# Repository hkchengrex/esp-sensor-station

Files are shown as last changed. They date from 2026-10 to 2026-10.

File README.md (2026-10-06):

# ESP Station

A USB-powered ESP32-C5 station with CO₂, temperature/humidity, radar presence,
and eight mechanical buttons. Firmware publishes MQTT telemetry and Home
Assistant discovery over TLS. Button events contain GPIO identifiers; assign
actions in your own automation system.

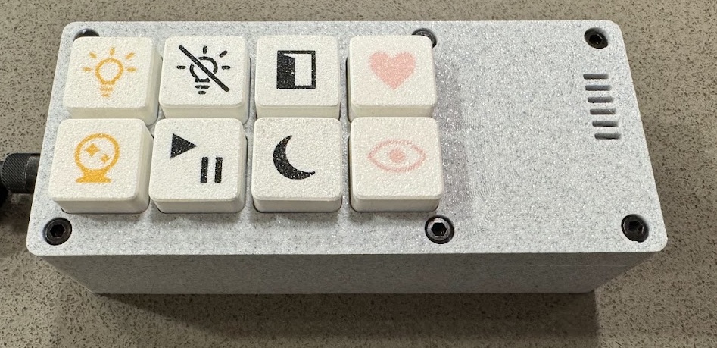
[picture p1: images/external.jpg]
External


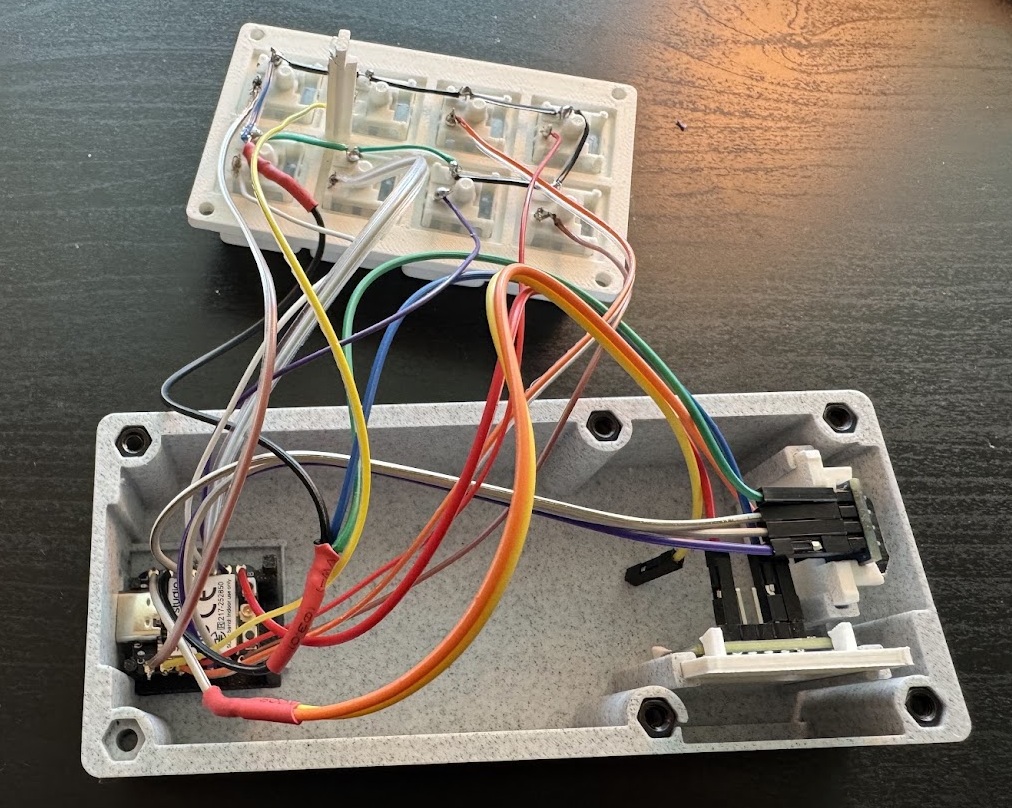
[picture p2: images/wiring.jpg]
Wiring

(forgive my poor soldering)

## Bill of materials

| Part | Quantity |
| --- | ---: |
| Seeed Studio XIAO ESP32-C5, with antenna | 1 |
| Sensirion SCD4x CO₂ sensor breakout, 3.3 V I²C | 1 |
| Hi-Link LD2410C radar module | 1 |
| MX-compatible mechanical switches | 8 |
| 3d printed parts | 1 set |

## Wiring

Wiring diagram

## Firmware

Use ESP-IDF **6.0.2**. Add your broker's public CA certificate as
`firmware/main/certs/mqtt_ca.crt`, then run from an ESP-IDF terminal:

```sh
cd firmware
idf.py set-target esp32c5
idf.py menuconfig
idf.py build
idf.py -p PORT flash
python tools/provision.py --port PORT wifi
python tools/provision.py --port PORT mqtt
```

Replace `PORT` with the board's USB serial port. Setup prompts for credentials;
passwords are hidden and saved only in the device's encrypted NVS. First boot
provisions an HMAC key in eFuse KEY0. See [wiring and firmware details](firmware/README.md).

## Models and printing

Editable FreeCAD models are in [`models/`](models/). Bambu Studio projects are in
[`print/`](print/):

- `01_Enclosure_and_Mounts_0.4mm.3mf`: base, lid, switch plate, ESP32 carrier,
  CO₂ carrier and radar carrier together on one plate.
- `02_Keycaps_AMS_0.2mm.3mf`: twelve distinct icons on one plate, with
  identical 18 × 18 × 9 mm bodies, white PLA and black inlays.

The enclosure plate uses a 0.4 mm nozzle. The keycap plate uses a 0.2 mm nozzle
and AMS. Select any eight icons for the station.

The icons are bulb, crossed bulb, moon, door, start/pause, heart, crystal ball,
eye, solid triangle, solid square, solid circle and arrow-door. Each icon appears
once in the [editable model and print project](models/README.md). Only the icon
differs; the outer profile and switch socket are shared by every cap.

Open the 3MF in Bambu Studio, select your printer/filaments and slice before
printing. Models retain their native editable features. The enclosure is
130 × 56 × 38 mm, excluding keycap height.

**Design limitation:** the base's top-open nut pockets do not capture the nuts
vertically, so the screw-fastened lid can lift out with them. Add a suitable
retention method before relying on the enclosure closure.

## License

Original firmware, tools and documentation: [MIT](LICENSES/MIT.txt).
Models, print projects and preview images: [CC0-1.0](LICENSES/CC0-1.0.txt).
Vendored sensor driver code retains its [third-party license](THIRD_PARTY.md).

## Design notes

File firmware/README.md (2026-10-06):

# Wiring and operation

Wiring diagram

| Connection | XIAO pad | GPIO |
| --- | --- | ---: |
| CO₂ SDA | D4 | 23 |
| CO₂ SCL | D5 | 24 |
| Radar TX → board RX | D7 | 12 |
| Button signals | D0, D1, D2, D3, D6, D8, D9, D10 | 1, 0, 25, 7, 11, 8, 9, 10 |

Power the SCD4x breakout from 3V3 and the LD2410C from 5V/VBUS. Connect both
sensor grounds directly to XIAO GND. The I²C pull-ups must use 3.3 V. The radar
uses UART1 at 256000 baud, 8N1; its RX and OUT pins are unused.

Each switch connects its GPIO to a shared switch return. Connect that return
to XIAO GND through one 1 kΩ resistor. Application UART logging is disabled.
The diagram shows the XIAO's top-view pad layout; sensor blocks are schematic.
Check the actual breakout pin labels before connecting power.

Buttons use internal pull-ups, 10 ms polling and 30 ms debounce. The event topic
reports both `press` and `release`; use `press` for immediate actions. Holding a
button does not repeat it. The separate action topic reports armed releases.
No physical button-to-function mapping is included.

The device identifies itself as `esp-c5-<MAC>` and publishes under
`esp-monitor/<device-id>/`:

| Suffix | Content |
| --- | --- |
| `availability` | Retained online/offline status |
| `state` | CO₂ ppm, temperature °C, humidity %, validity and sample time |
| `presence` | Moving/occupied flags, validity and distance |
| `buttons/event` | GPIO, pad, press/release, boot ID and sequence |
| `buttons/action` | Accepted release actions |
| `buttons/status` | Input mask, debounce/poll intervals and dropped-event counts |
| `calibration/command`, `calibration/result` | Guarded SCD4x calibration requests/results |

Air readings publish every 30 seconds; presence updates every 200 ms. Deduplicate
button events by `(boot_id, sequence)`. MQTT uses QoS 1 and button events are not
retained. The onboard LED follows fresh moving-target reports independently of
network connectivity. Wi-Fi modem power saving remains enabled.

`tools/provision.py` requires `pyserial` (`python -m pip install -r tools/requirements.txt`).
Create a broker user before MQTT setup and grant it access to its device namespace
and the Home Assistant discovery topics. Provision Wi-Fi first, then MQTT. The
broker CA is compiled into the firmware; credentials are entered locally over USB.

For an already provisioned board with this partition layout, update only the app:

```sh
idf.py build
python -m esptool --chip esp32c5 --port PORT --before usb-reset --after hard-reset write-flash --flash-mode dio --flash-size 8MB --flash-freq 80m 0x10000 build/esp_station.bin
python tests/hardware_usb.py --port PORT --cycles 0
```

The C5 rev1.0 USB-reset clock workaround is included. Never erase flash merely
to update the app; doing so removes saved credentials. OTA is not configured.
The optional UDP movement receiver is disabled by default.

Host checks (Linux/WSL with a C compiler):

```sh
python3 tests/host/test_components.py
cc -std=c11 -Wall -Wextra -Werror -Imain tests/test_radar.c main/radar.c -o /tmp/station-radar
/tmp/station-radar
cc -std=c11 -Wall -Wextra -Werror -Imain tests/test_buttons.c -o /tmp/station-buttons
/tmp/station-buttons
python3 -m unittest discover -s tests -p test_provision.py
```

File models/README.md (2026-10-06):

# Models and printing

Open `Station.FCStd` in FreeCAD 1.1 for the base, lid, switch plate and carriers.
Open `Keycaps.FCStd` for the twelve keycaps. Each named icon group contains its
native editable body, sketches and inlays. The station document's eight keycaps
are assembly references. Editing CAD does not automatically update the saved 3MF.

## Keycaps

`../print/02_Keycaps_AMS_0.2mm.3mf` contains one of each icon on a single plate.
Every cap has the same 18 × 18 × 9 mm outer profile, skirt and MX socket.

| Plate row, front to back | Icons, left to right |
| --- | --- |
| 1 | Bulb, crossed bulb, moon, door |
| 2 | Start/pause, heart, crystal ball, eye |
| 3 | Solid triangle, solid square, solid circle, arrow-door |

Use the A1 0.2 mm nozzle, 0.10 mm layers, four walls, 20% gyroid, no supports or
object brim, and a prime tower. Keep the face-down orientation. Slot 1 is white
PLA; slot 2 is black PLA for the 0.52 mm deep inlays. Colour-change purge volumes
are 172 mm³ white to black and 652 mm³ black to white. Select the eight icons you
want, or print all twelve.

## Enclosure and mounts

The base, lid, switch plate and all three electronics carriers share one plate in
`../print/01_Enclosure_and_Mounts_0.4mm.3mf`: 0.16 mm layers, four walls,
20% gyroid, and no support or brim. Keep the stored orientations.

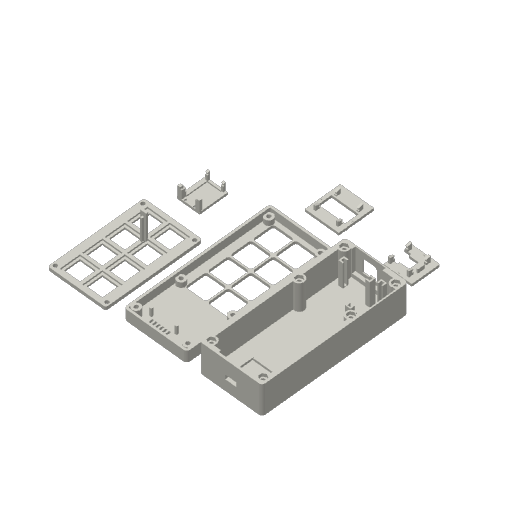
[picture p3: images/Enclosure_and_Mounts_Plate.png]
Enclosure and mounts plate


Both projects have been sliced and reopened through Bambu Studio's CLI. Desktop
preset persistence has not been checked. On opening, confirm the nozzle, layer
height, walls, infill, supports, brim and filament slots above before printing.

The base has open nut pockets without vertical capture. Its lid needs an added
retention method. Test switch socket and carrier fit with your hardware; fit and
material performance depend on the printer and electronics breakout.

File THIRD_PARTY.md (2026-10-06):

# Third-party code

`firmware/vendor/scd4x/` contains the Sensirion SCD4x I²C driver at commit
`b52cebe1bb1b7050feaac75d7cd33e56c6a8a4e9` from
[Sensirion/embedded-i2c-scd4x](https://github.com/Sensirion/embedded-i2c-scd4x).
Its BSD-3-Clause license and copyright notices are preserved in that directory.

ESP-IDF and the locked Espressif MQTT/cJSON components are downloaded by the
build system and retain their respective licenses; they are not bundled here.

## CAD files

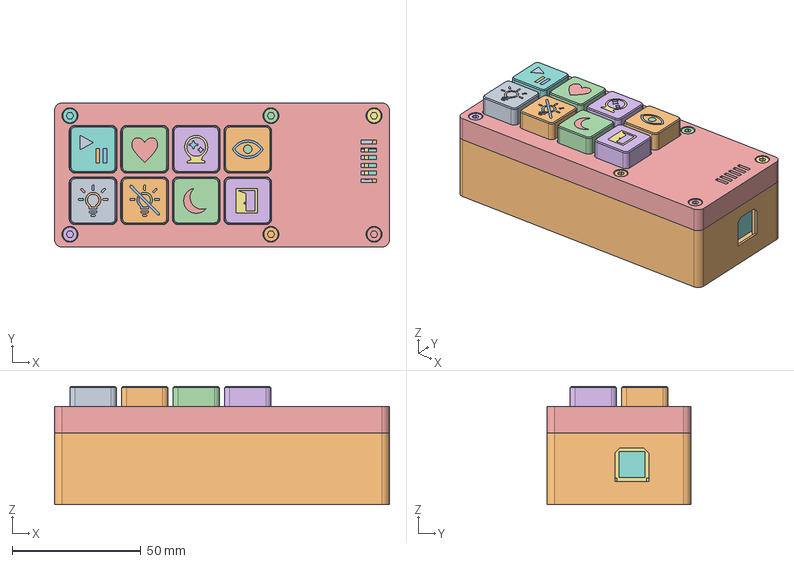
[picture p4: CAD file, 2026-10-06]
models/Station.FCStd
130.0 x 56.0 x 45.9 mm
Removable XIAO carrier - USB-C to left
01 Base - sensor guide rails and left USB-C
REFERENCE - XIAO bare PCB
03 Switch plate - eight switches and ESP32 hold-down
02 Lid - sensor retention, six shared screws
REFERENCE switch 1 - approximate housing
REFERENCE switch 1 stem
REFERENCE switch 2 - approximate housing
REFERENCE switch 2 stem
REFERENCE switch 3 - approximate housing
REFERENCE switch 3 stem
REFERENCE switch 4 - approximate housing
REFERENCE switch 4 stem
REFERENCE switch 5 - approximate housing
REFERENCE switch 5 stem
REFERENCE switch 6 - approximate housing
REFERENCE switch 6 stem
REFERENCE switch 7 - approximate housing
REFERENCE switch 7 stem
REFERENCE switch 8 - approximate housing
REFERENCE switch 8 stem
REFERENCE M3 x 10 socket screw 1
REFERENCE M3 nut 1
REFERENCE M3 x 10 socket screw 2
REFERENCE M3 nut 2
REFERENCE M3 x 10 socket screw 3
REFERENCE M3 nut 3
REFERENCE M3 x 10 socket screw 4
REFERENCE M3 nut 4
REFERENCE XIAO shield
REFERENCE USB socket
03 Radar carrier - tapered anti-rattle contact ribs
04 CO2 carrier - tapered anti-rattle contact ribs
REFERENCE Radar_PCB
REFERENCE Radar_Header
REFERENCE 30 x 12 mm FPC antenna, final antenna size and routing pending
REFERENCE M3 x 10 screw 5
REFERENCE M3 nut 5
REFERENCE M3 x 10 screw 6
REFERENCE M3 nut 6
CO2 rear straight header - 4 x 2.54 mm
CO2 4-pin plug allowance 11.2 x 4; 16 mm total rear projection
CO2 straight pin 1
CO2 straight pin 2
CO2 straight pin 3
CO2 straight pin 4
REFERENCE CO2 PCB - measured 21.75 mm height
REFERENCE CO2 sensor - 2.10 mm from PCB bottom
REFERENCE 1. Light bulb body
REFERENCE 1. Light bulb inlay 1
REFERENCE 1. Light bulb inlay 2
REFERENCE 1. Light bulb inlay 3
REFERENCE 1. Light bulb inlay 4
REFERENCE 1. Light bulb inlay 5
REFERENCE 1. Light bulb inlay 6
REFERENCE 1. Light bulb inlay 7
REFERENCE 1. Light bulb inlay 8
REFERENCE 2. Light bulb off body
REFERENCE 2. Light bulb off inlay 1
REFERENCE 2. Light bulb off inlay 2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

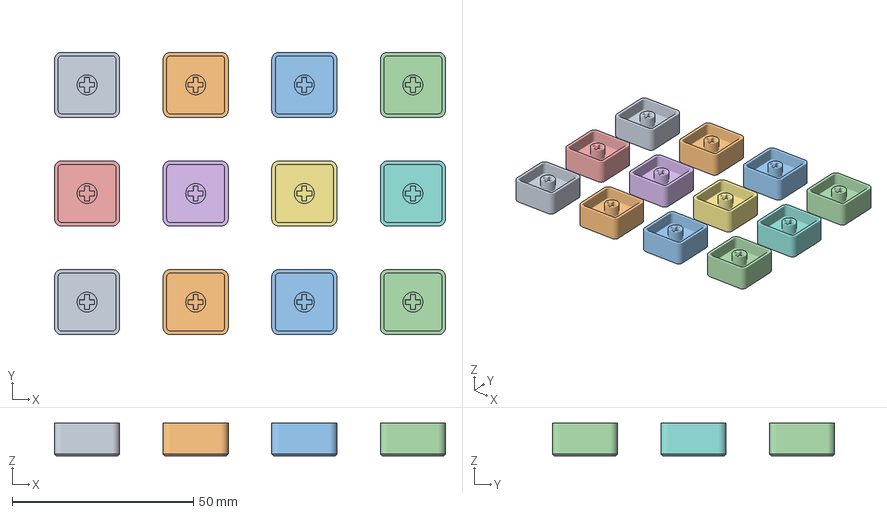
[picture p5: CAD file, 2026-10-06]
print/02_Keycaps_AMS_0.2mm.3mf
108.0 x 78.0 x 9.00 mm
01 Bulb
02 Crossed bulb
03 Moon
04 Door
05 Start pause
06 Heart
07 Crystal ball
08 Eye
09 Triangle
10 Square
11 Circle
12 Arrow door

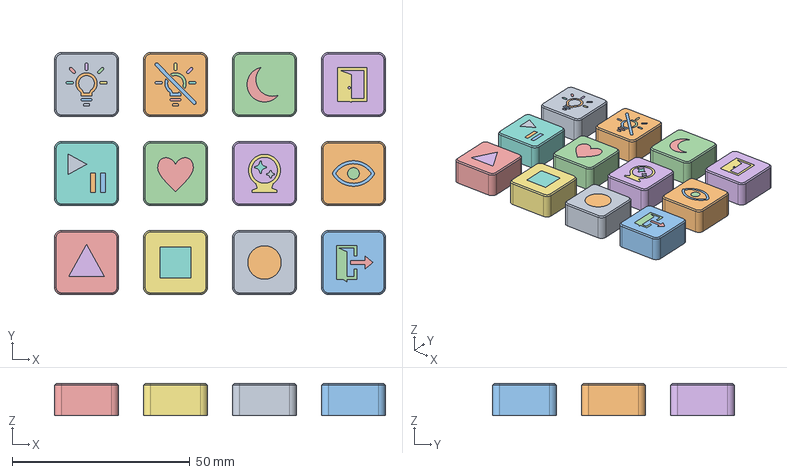
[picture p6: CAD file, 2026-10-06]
models/Keycaps.FCStd
93.0 x 68.0 x 9.00 mm
Bulb - body
Bulb - icon 1
Bulb - icon 2
Bulb - icon 3
Bulb - icon 4
Bulb - icon 5
Bulb - icon 6
Bulb - icon 7
Bulb - icon 8
Crossed bulb - body
Crossed bulb - icon 1
Crossed bulb - icon 2
Crossed bulb - icon 3
Crossed bulb - icon 4
Crossed bulb - icon 5
Crossed bulb - icon 6
Crossed bulb - icon 7
Crossed bulb - icon 8
Crossed bulb - icon 9
Moon - body
Moon - icon 1
Door - body
Door - icon 1
Start pause - body
Start pause - icon 1
Start pause - icon 2
Start pause - icon 3
Heart - body
Heart - icon 1
Crystal ball - body
Crystal ball - icon 1
Crystal ball - icon 2
Crystal ball - icon 3
Eye - body
Eye - icon 1
Eye - icon 2
Triangle - body
Triangle - icon 1
Square - body
Square - icon 1
Circle - body
Circle - icon 1
Arrow door - body
Arrow door - icon 1
Arrow door - icon 2

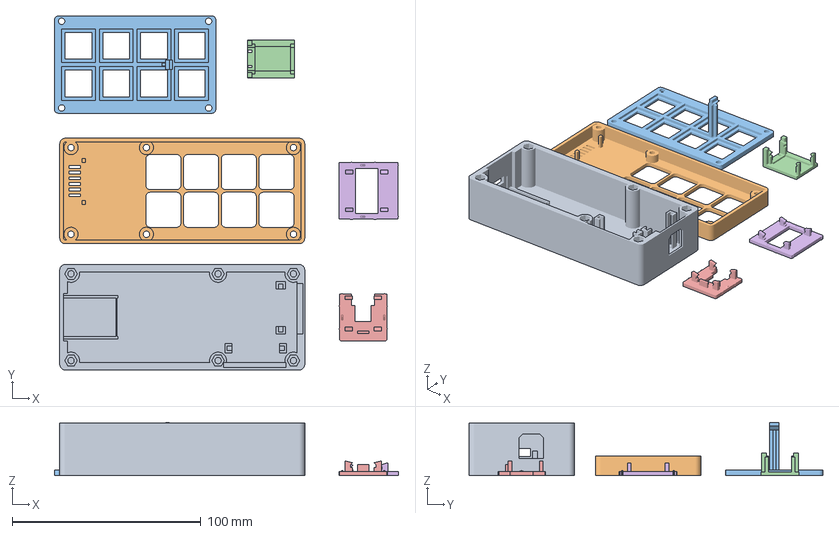
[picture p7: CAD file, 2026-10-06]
print/01_Enclosure_and_Mounts_0.4mm.3mf
182.5 x 187.8 x 28.2 mm
Base
Lid
Switch plate
ESP32 carrier
CO2 carrier
Radar carrier

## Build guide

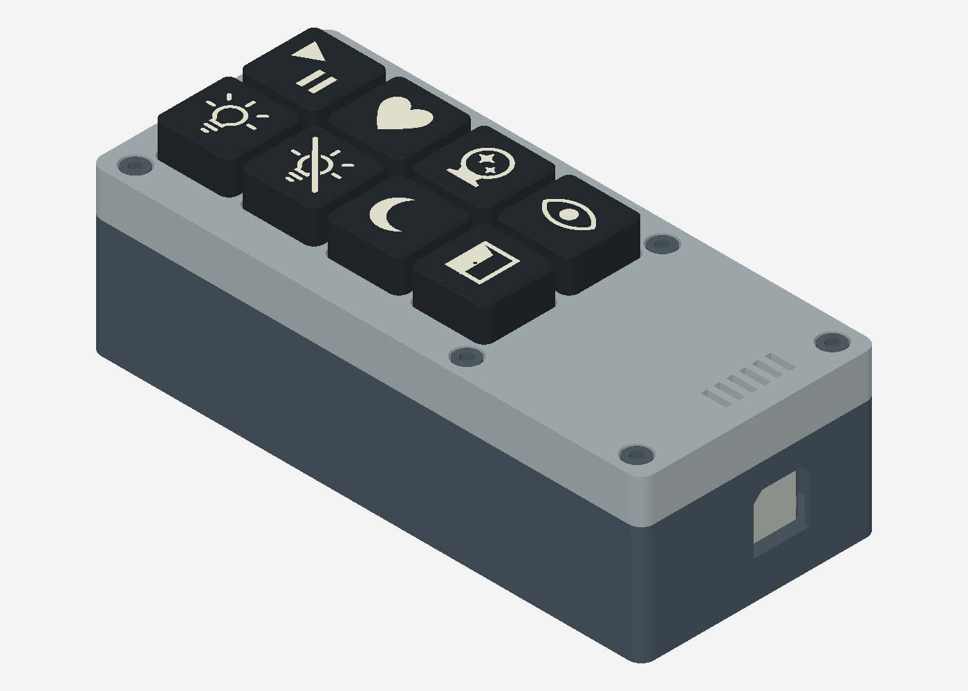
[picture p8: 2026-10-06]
images/Station_Assembly.png

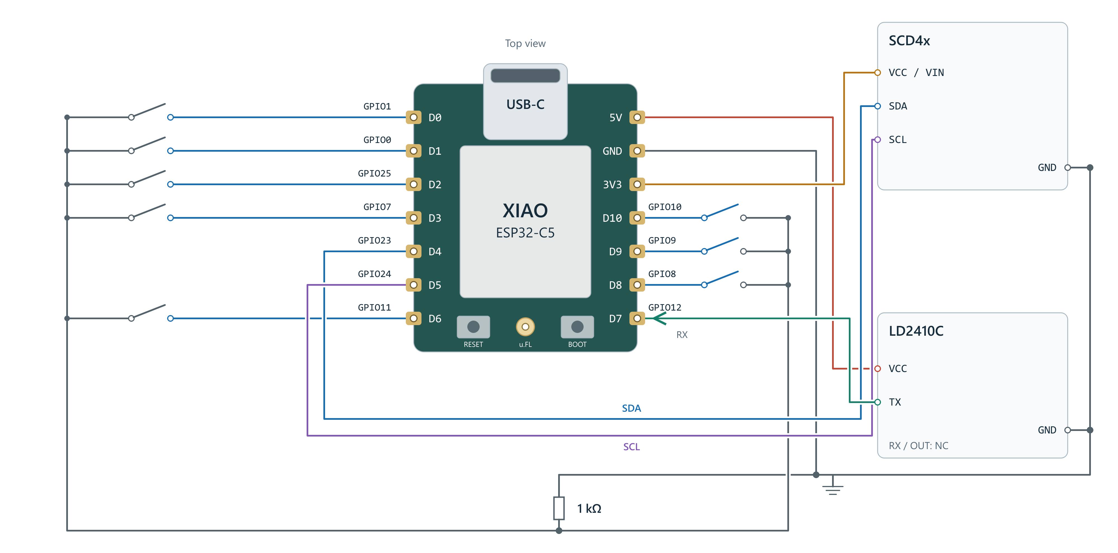
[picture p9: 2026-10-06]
images/Wiring_Diagram.png

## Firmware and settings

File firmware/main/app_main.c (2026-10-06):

#include <inttypes.h>
#include <stdio.h>
#include <time.h>
#include "credential_store.h"
#include "station.h"
#include "buttons.h"
#include "wifi_manager.h"
#include "mqtt_connection.h"
#include "ha_discovery.h"
#include "usb_provisioning.h"
#include "esp_event.h"
#include "esp_chip_info.h"
#include "esp_private/startup_internal.h"
#include "hal/uart_ll.h"
#include "esp_log.h"
#include "esp_mac.h"
#include "esp_netif.h"
#include "esp_netif_sntp.h"
#include "esp_timer.h"
#include "esp_wifi.h"
#include "freertos/FreeRTOS.h"
#include "freertos/task.h"

// ESP32-C5 rev1.0 ROM waits for UART0_READY even when flashing over USB.
// IDF 6.0.2 gates this clock when the UART console is disabled; a USB core
// reset preserves that state and then hangs in ROM. Restore only the clocks
// early in startup. Do not install UART0 or route its TX onto button GPIO11.
// https://github.com/espressif/esp-idf/issues/18089
ESP_SYSTEM_INIT_FN(keep_c5_usb_reset_working, CORE, BIT(0), 100)
{
    esp_chip_info_t chip;
    esp_chip_info(&chip);
    if (chip.model == CHIP_ESP32C5 && chip.revision == 100) {
        uart_ll_enable_bus_clock(UART_NUM_0, true);
        uart_ll_sclk_enable(UART_LL_GET_HW(UART_NUM_0));
    }
    return ESP_OK;
}

extern const uint8_t mqtt_ca_crt_start[] asm("_binary_mqtt_ca_crt_start");
static char s_device_id[32];
static char s_state_topic[128];
static char s_availability_topic[128];
static const char *TAG = "esp_monitor";

static bool time_ready(void)
{
    return time(NULL) > 1735689600;
}

static bool wait_for_time(void)
{
    return time_ready() || esp_netif_sntp_sync_wait(pdMS_TO_TICKS(15000)) == ESP_OK;
}

static void application_task(void *arg)
{
    (void)arg;
    uint32_t published_generation = 0;

    int64_t next_start = 0;
    for (;;) {
        int64_t now = esp_timer_get_time();
        if (wifi_manager_is_connected() && time_ready() && now >= next_start) {
            // Handles delayed Wi-Fi or clock recovery even when boot was offline.
            (void)mqtt_connection_start_saved();
            next_start = now + 5000000;
        }
        if (mqtt_connection_is_connected()) {
            uint32_t generation = mqtt_connection_generation();
            if (station_publish(generation != published_generation) == ESP_OK)
                published_generation = generation;
        }
        vTaskDelay(pdMS_TO_TICKS(200));
    }
}

void app_main(void)
{
    ESP_ERROR_CHECK(usb_provisioning_initialize(wait_for_time));
    usb_provisioning_send("\nESP32-C5 indoor sensor station\n");
    // Provision HMAC KEY0 for encrypted NVS on first boot; never erase NVS on failure.
    ESP_ERROR_CHECK(credential_store_init(true));
    ESP_LOGI(TAG, "Encrypted NVS ready");
    ESP_ERROR_CHECK(esp_netif_init());
    ESP_ERROR_CHECK(esp_event_loop_create_default());
    ESP_ERROR_CHECK(wifi_manager_initialize("esp32-station"));
    // Keep modem power saving; the fast MQTT outbox poll removes sender delays.
    ESP_ERROR_CHECK(esp_wifi_set_ps(WIFI_PS_MIN_MODEM));
    uint8_t mac[6];
    ESP_ERROR_CHECK(esp_read_mac(mac, ESP_MAC_WIFI_STA));
    snprintf(s_device_id, sizeof(s_device_id), "esp-c5-%02x%02x%02x%02x%02x%02x",
             mac[0], mac[1], mac[2], mac[3], mac[4], mac[5]);
    snprintf(s_state_topic, sizeof(s_state_topic), "esp-monitor/%s/state", s_device_id);
    snprintf(s_availability_topic, sizeof(s_availability_topic), "esp-monitor/%s/availability", s_device_id);
    ESP_ERROR_CHECK(station_initialize(s_device_id));
    static char command_topic[128];
    snprintf(command_topic,sizeof(command_topic),"esp-monitor/%s/calibration/command",s_device_id);
    const mqtt_connection_options_t options = {
        .device_id = s_device_id, .ca_certificate = (const char *)mqtt_ca_crt_start,
        .availability_topic = s_availability_topic,
        .command_topic = command_topic, .on_message = station_receive,
        .outbox_limit_bytes = 32768,
    };
    ESP_ERROR_CHECK(mqtt_connection_initialize(&options));
    // Keep SNTP alive so an initial network outage does not prevent TLS forever.
    esp_sntp_config_t sntp = ESP_NETIF_SNTP_DEFAULT_CONFIG("pool.ntp.org");
    sntp.start = false;
    sntp.server_from_dhcp = false;
    sntp.renew_servers_after_new_IP = true;
    sntp.ip_event_to_renew = IP_EVENT_STA_GOT_IP;
    ESP_ERROR_CHECK(esp_netif_sntp_init(&sntp));
    ESP_ERROR_CHECK(esp_netif_sntp_start());
    esp_err_t error = wifi_manager_start_saved();
    usb_provisioning_send(error == ESP_OK ? "WIFI_CONNECTING_SAVED\n" : "WIFI_SETUP_REQUIRED\n");
    if (xTaskCreate(application_task, "app_telemetry", 10240, NULL, 5, NULL) != pdPASS) {
        ESP_ERROR_CHECK(ESP_ERR_NO_MEM);
    }
    usb_provisioning_set_command_handler(buttons_usb_command);
    usb_provisioning_run();
}

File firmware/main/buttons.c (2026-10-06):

#include "buttons.h"
#include "button_filter.h"
#include "driver/gpio.h"
#include "driver/usb_serial_jtag.h"
#include "usb_provisioning.h"
#include "esp_timer.h"
#include "mqtt_connection.h"
#include "freertos/FreeRTOS.h"
#include "freertos/queue.h"
#include "freertos/task.h"
#include <inttypes.h>
#include <stdio.h>
#include <string.h>

static const int pins[]={1,0,25,7,11,8,9,10};
static const char *pads[]={"D0","D1","D2","D3","D6","D8","D9","D10"};
static char event_topic[128], action_topic[128], status_topic[128], boot_id[33];
typedef struct { uint32_t sequence; int64_t at_us; uint8_t mask,index; bool pressed, activate; } event_t;
typedef struct { uint32_t sequence,dropped; uint8_t mask; } status_t;
static QueueHandle_t events, usb_events;
// An active USB monitor renews this lease; closing it cannot leave an endless
// diagnostic stream or block normal sensor/MQTT operation.
static int64_t usb_watch_until_us;
static uint32_t usb_dropped;
static portMUX_TYPE state_lock=portMUX_INITIALIZER_UNLOCKED;
static status_t status;
static button_filter_t levels[8];
static uint32_t sampled_changes[8], poll_count;

_Static_assert(pdMS_TO_TICKS(BUTTON_POLL_MS)>0, "Button polling requires a tick of 10 ms or faster");
_Static_assert((BUTTON_POLL_MS*configTICK_RATE_HZ)%1000==0, "Button polling period must be a whole number of ticks");

static void poll_buttons(void *unused) {
    (void)unused;
    TickType_t wake=xTaskGetTickCount();
    for(;;) {
        // One scan per 10 ms in a dedicated task. No GPIO interrupts, network
        // calls, USB writes or sensor telemetry work run in this task.
        portENTER_CRITICAL(&state_lock);
        uint64_t now=(uint64_t)esp_timer_get_time();
        poll_count++;
        for(unsigned i=0;i<8;i++) {
            bool raw_pressed=gpio_get_level(pins[i])==0;
            if(raw_pressed!=levels[i].candidate) sampled_changes[i]++;
            button_change_t change=button_filter_update(&levels[i],raw_pressed,now);
            if(change.edge!=BUTTON_NO_EDGE) {
                bool pressed=change.edge==BUTTON_PRESSED;
                if(pressed) status.mask|=1u<<i; else status.mask&=~(1u<<i);
                event_t event={.sequence=++status.sequence,.at_us=(int64_t)now,
                    .mask=status.mask,.index=i,.pressed=pressed,.activate=change.activate};
                if(xQueueSend(events,&event,0)!=pdTRUE) status.dropped++;
                if(change.activate && (int64_t)now<usb_watch_until_us) {
                    if(xQueueSend(usb_events,&event,0)!=pdTRUE) usb_dropped++;
                }
            }
        }
        portEXIT_CRITICAL(&state_lock);
        // Fixed-rate scheduling avoids accumulating scan-time drift. After a
        // missed deadline, resume from now instead of replaying old scans.
        if(xTaskDelayUntil(&wake,pdMS_TO_TICKS(BUTTON_POLL_MS))==pdFALSE)
            wake=xTaskGetTickCount();
    }
}

bool buttons_usb_command(const char *command) {
    if(strcmp(command,"BUTTONS_STATE")==0) {
        // Read-only snapshots distinguish unstable wiring from transport or
        // debounce faults. They do not alter the filter, GPIO or action state.
        for(unsigned i=0;i<8;i++) {
            button_filter_t filter;
            uint32_t count, scans;
            int raw;
            int64_t now;
            portENTER_CRITICAL(&state_lock);
            filter=levels[i]; count=sampled_changes[i]; scans=poll_count;
            raw=gpio_get_level(pins[i]); now=esp_timer_get_time();
            portEXIT_CRITICAL(&state_lock);
            gpio_io_config_t cfg={0};
            esp_err_t err=gpio_get_io_config(pins[i],&cfg);
            char line[384];
            int length=snprintf(line,sizeof(line),
                "BUTTON_STATE {\"boot_id\":\"%s\",\"gpio\":%d,\"pad\":\"%s\",\"uptime_ms\":%"PRId64",\"raw_level\":%d,\"pressed\":%d,\"candidate_pressed\":%d,\"armed\":%d,\"sampled_changes\":%"PRIu32",\"poll_count\":%"PRIu32",\"change_age_us\":%"PRId64",\"pullup\":%d,\"pulldown\":%d,\"input\":%d,\"output\":%d,\"function\":%"PRIu32",\"config_error\":%d}\n",
                boot_id,pins[i],pads[i],now/1000,raw,filter.stable,filter.candidate,filter.armed,count,scans,
                now-(int64_t)filter.changed_us,cfg.pu,cfg.pd,cfg.ie,cfg.oe,cfg.fun_sel,(int)err);
            if(length>0 && length<(int)sizeof(line))
                (void)usb_serial_jtag_write_bytes(line,length,pdMS_TO_TICKS(20));
        }
        return true;
    }
    bool watch=strcmp(command,"BUTTONS_WATCH")==0;
    bool stop=strcmp(command,"BUTTONS_STOP")==0;
    if(!watch && !stop) return false;
    portENTER_CRITICAL(&state_lock);
    usb_watch_until_us=watch ? esp_timer_get_time()+5000000 : 0;
    portEXIT_CRITICAL(&state_lock);
    usb_provisioning_send(watch ? "BUTTONS_WATCHING debounce_ms=30 trigger=rising poll_ms=10 reporting=polling_debounced\n" : "BUTTONS_STOPPED\n");
    return true;
}

static void publish_usb_edges(void *unused) {
    (void)unused;
    event_t event;
    for(;;) {
        if(xQueueReceive(usb_events,&event,portMAX_DELAY)!=pdTRUE) continue;
        int64_t now=esp_timer_get_time();
        portENTER_CRITICAL(&state_lock);
        bool active=now<usb_watch_until_us;
        portEXIT_CRITICAL(&state_lock);
        if(!active) continue;
        char line[128];
        int length=snprintf(line,sizeof(line),
            "BUTTON gpio=%d pad=%s sequence=%"PRIu32" event_us=%"PRId64" age_us=%"PRId64"\n",
            pins[event.index],pads[event.index],event.sequence,event.at_us,now-event.at_us);
        // Independent of MQTT and its outbox: an offline/slow network cannot
        // delay the local pin test. A full USB buffer drops instead of waits.
        if(usb_serial_jtag_write_bytes(line,length,0)!=length) {
            portENTER_CRITICAL(&state_lock); usb_dropped++; portEXIT_CRITICAL(&state_lock);
        }
    }
}
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

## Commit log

2026-10-06 Initial station release
    [01_Enclosure_and_Mounts_0.4mm.3mf, 02_Keycaps_AMS_0.2mm.3mf, Keycaps.FCStd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]
2026-10-06 Add station wiring diagram and shared switch return instructions
